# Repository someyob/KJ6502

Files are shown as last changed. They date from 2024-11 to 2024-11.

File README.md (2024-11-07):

# KJ6502
Inspired by the Ben Eater video series.

Note:  the expension header has 2 errors, Pins 15 through 21 should be
A12, A13, A14 and A15 respectively.  These are not intended to be used anyway.



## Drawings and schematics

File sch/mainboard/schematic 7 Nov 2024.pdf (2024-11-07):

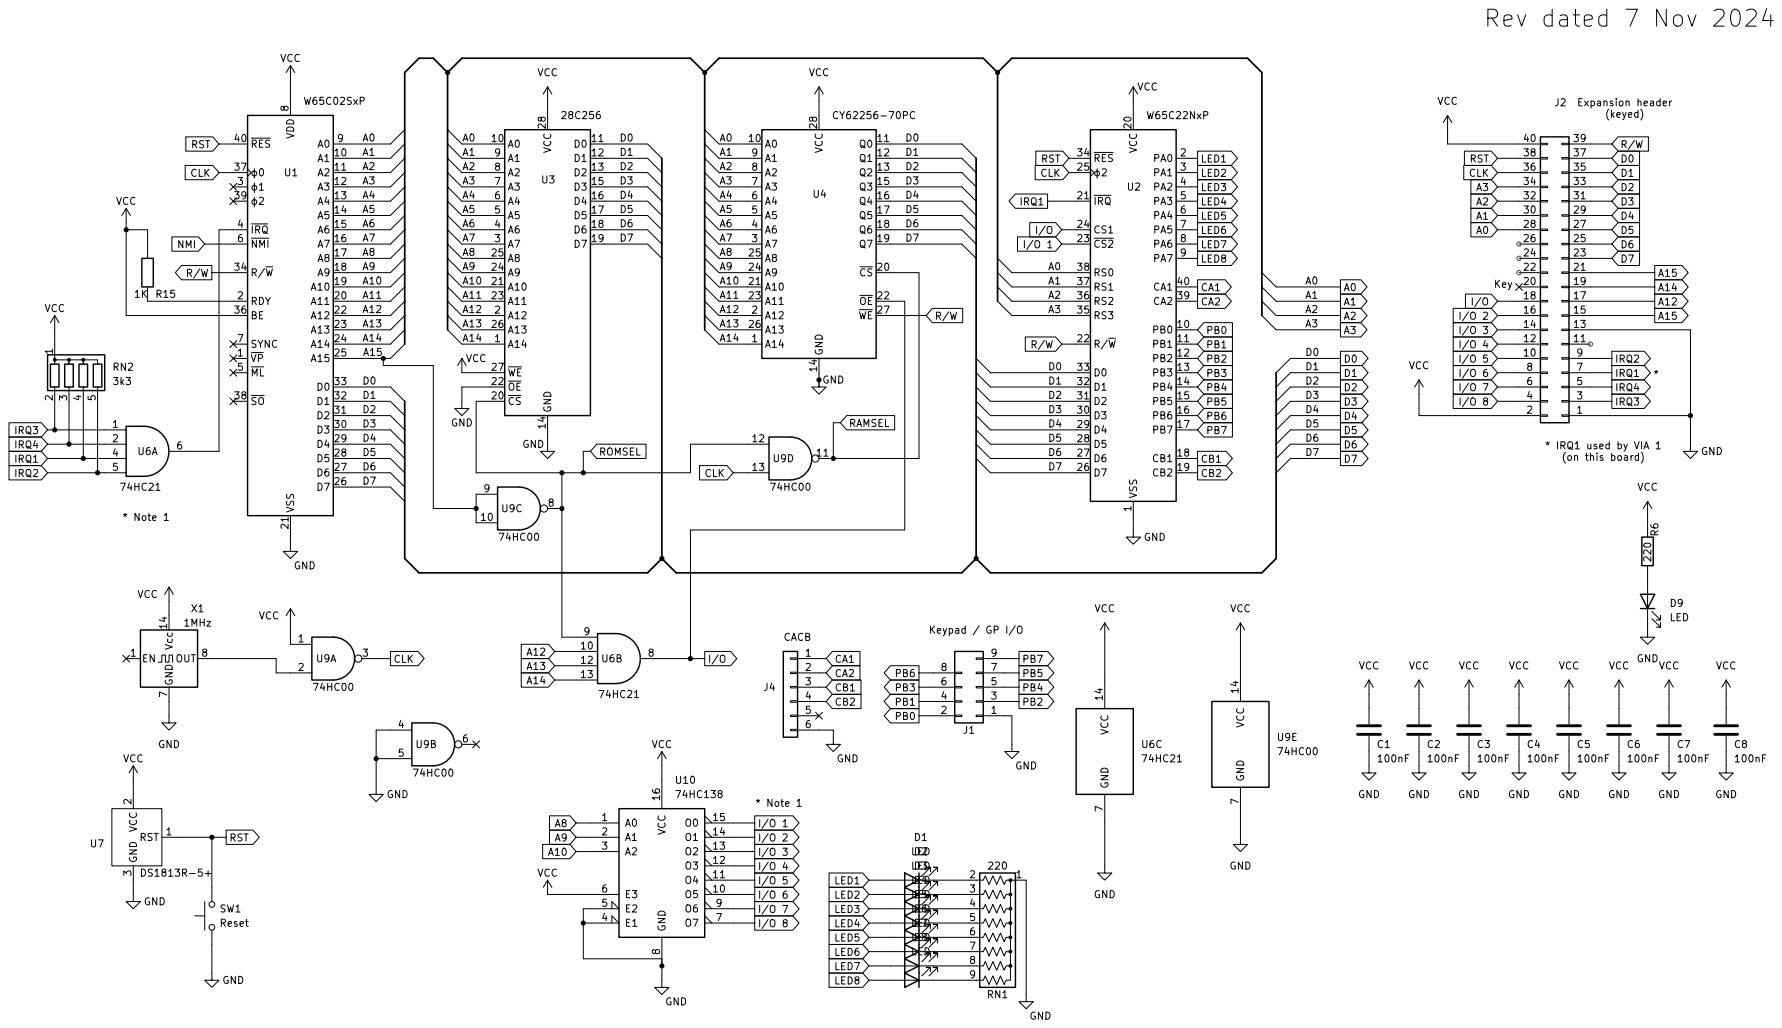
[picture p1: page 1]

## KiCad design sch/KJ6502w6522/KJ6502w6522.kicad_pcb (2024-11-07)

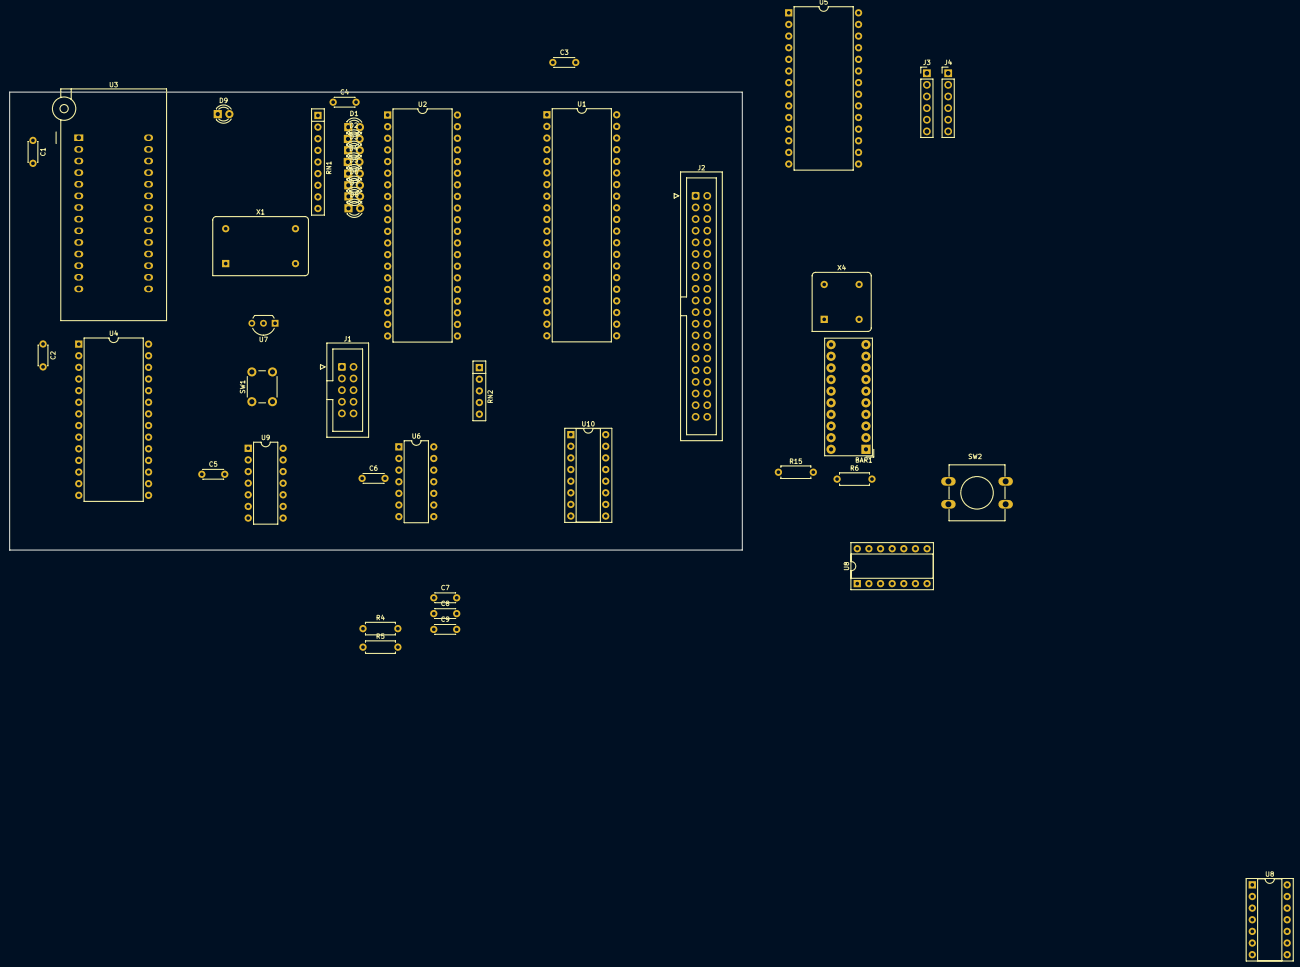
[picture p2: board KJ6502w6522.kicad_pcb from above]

Board: 2 copper layers, 160.0 x 100.0 mm, 44 parts (0 on the bottom side), 75 nets, no tracks yet.

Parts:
BAR1: HDSP-4830_2; HDSP-4830
C1, C2, C3, C4, C5, C6, C7, C8, C9: 100nF; C_Disc_D4.3mm_W1.9mm_P5.00mm
D1, D2, D3, D4, D5, D6, D7, D8, D9: LED; LED_D3.0mm
J1: Keypad / GP I/O; IDC-Header_2x05_P2.54mm_Vertical
J2: Conn_02x20_Odd_Even; IDC-Header_2x20_P2.54mm_Vertical
J3: Serial; PinHeader_1x06_P2.54mm_Vertical
J4: CACB; PinHeader_1x06_P2.54mm_Vertical
R4, R5: 10K; R_Axial_DIN0207_L6.3mm_D2.5mm_P7.62mm_Horizontal
R6: 220; R_Axial_DIN0207_L6.3mm_D2.5mm_P7.62mm_Horizontal
R15: 1K; R_Axial_DIN0207_L6.3mm_D2.5mm_P7.62mm_Horizontal
RN1: 220; R_Array_SIP9
RN2: 3k3; R_Array_SIP5
SW1: Reset; SW_PUSH_6mm
SW2: NMI; SW_PUSH-12mm
U1: W65C02SxP; DIP-40_W15.24mm
U2: W65C22NxP; DIP-40_W15.24mm
U3: 28C256; DIP_Socket-28_W11.9_W12.7_W15.24_W17.78_W18.5_3M_228-1277-0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
U4: CY62256-70PC; DIP-28_W15.24mm
U5: W65C51NxP; DIP-28_W15.24mm
U6: 74HC21; DIP-14_W7.62mm
U7: TO-92L_Inline_Wide
U8, U8#2: 74HC14; DIP-14_W7.62mm_Socket
U9: 74HC00; DIP-14_W7.62mm
U10: 74HC138; DIP-16_W7.62mm_Socket
X1: 1MHz; Oscillator_DIP-14
X4: TFT660; Oscillator_DIP-8

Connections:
/A0: U1.9 (A0), U2.38 (RS0), U3.10 (A0), U4.10 (A0), U5.13 (RS0)
/A1: U1.10 (A1), U2.37 (RS1), U3.9 (A1), U4.9 (A1), U5.14 (RS1)
/A2: U1.11 (A2), U2.36 (RS2), U3.8 (A2), U4.8 (A2)
/A3: U1.12 (A3), U2.35 (RS3), U3.7 (A3), U4.7 (A3)
/A4: U1.13 (A4), U3.6 (A4), U4.6 (A4)
/A5: U1.14 (A5), U3.5 (A5), U4.5 (A5)
/A6: U1.15 (A6), U3.4 (A6), U4.4 (A6)
/A7: U1.16 (A7), U3.3 (A7), U4.3 (A7)
/A11: U1.20 (A11), U3.23 (A11), U4.23 (A11)
/A15: U1.25 (A15), U9.9, U9.10
/D0: U1.33 (D0), U2.33 (D0), U3.11 (D0), U4.11 (Q0), U5.18 (D0)
/D1: U1.32 (D1), U2.32 (D1), U3.12 (D1), U4.12 (Q1), U5.19 (D1)
/D2: U1.31 (D2), U2.31 (D2), U3.13 (D2), U4.13 (Q2), U5.20 (D2)
/D3: U1.30 (D3), U2.30 (D3), U3.15 (D3), U4.15 (Q3), U5.21 (D3)
/D4: U1.29 (D4), U2.29 (D4), U3.16 (D4), U4.16 (Q4), U5.22 (D4)
/D5: U1.28 (D5), U2.28 (D5), U3.17 (D5), U4.17 (Q5), U5.23 (D5)
/D6: U1.27 (D6), U2.27 (D6), U3.18 (D6), U4.18 (Q6), U5.24 (D6)
/D7: U1.26 (D7), U2.26 (D7), U3.19 (D7), U4.19 (Q7), U5.25 (D7)
A8: U1.17 (A8), U3.25 (A8), U4.25 (A8), U10.1 (A0)
A9: U1.18 (A9), U3.24 (A9), U4.24 (A9), U10.2 (A1)
A10: U1.19 (A10), U3.21 (A10), U4.21 (A10), U10.3 (A2)
A12: U1.22 (A12), U3.2 (A12), U4.2 (A12), U6.10
A13: U1.23 (A13), U3.26 (A13), U4.26 (A13), U6.12
A14: U1.24 (A14), U3.1 (A14), U4.1 (A14), U6.13
CA1: J4.1, U2.40 (CA1)
CA2: J4.2, U2.39 (CA2)
CB1: J4.3, U2.18 (CB1)
CB2: J4.4, U2.19 (CB2)
CLK: U1.37 (ϕ0), U2.25 (ϕ2), U5.27 (ϕ2), U9.13, X1.8 (OUT)
GND: C1.2, C2.2, C3.2, C4.2, C5.2, C6.2, C7.2, C8.2, C9.2, D9.1 (K), J1.1, J3.2, J4.6, RN1.1 (common), SW1.1, SW2.1, U1.21 (VSS), U2.1 (VSS), U3.14 (GND), U3.22 (~OE), U4.14 (GND), U5.1 (VSS), U5.9 (~CTS), U5.16 (~DCD), U5.17 (~DSR), U6.7 (GND), U7.3 (GND), U9.7 (GND), U10.4 (E1), U10.5 (E2), U10.8 (GND), X1.7 (GND), X4.4 (GND)
IRQ1: RN2.4 (R3), U2.21 (~IRQ), U6.4
IRQ2: RN2.5 (R4), U5.26 (~IRQ), U6.5
IRQ3: RN2.2 (R1), U6.1
IRQ4: RN2.3 (R2), U6.2
I/O: U2.24 (CS1), U4.22 (~OE), U5.2 (CS1), U6.8
I/O 1: U2.23 (~CS2), U10.15 (O0)
I/O 2: U5.3 (~CS2), U10.14 (O1)
LED1: BAR1.3 (A), D1.2 (A), U2.2 (PA0)
LED2: BAR1.4 (A), D2.2 (A), U2.3 (PA1)
LED3: BAR1.5 (A), D3.2 (A), U2.4 (PA2)
LED4: BAR1.6 (A), D4.2 (A), U2.5 (PA3)
LED5: BAR1.7 (A), D5.2 (A), U2.6 (PA4)
LED6: BAR1.8 (A), D6.2 (A), U2.7 (PA5)
LED7: BAR1.9 (A), D7.2 (A), U2.8 (PA6)
LED8: BAR1.10 (A), D8.2 (A), U2.9 (PA7)
NMI: U1.6 (~NMI), U8#2.12
unnamed: C9.1, R5.1, U8#2.13
unnamed: D1.1 (K), RN1.2 (R1)
unnamed: D2.1 (K), RN1.3 (R2)
unnamed: D3.1 (K), RN1.4 (R3)
unnamed: D4.1 (K), RN1.5 (R4)
unnamed: D5.1 (K), RN1.6 (R5)
unnamed: D6.1 (K), RN1.7 (R6)
unnamed: D7.1 (K), RN1.8 (R7)
unnamed: D8.1 (K), RN1.9 (R8)
unnamed: D9.2 (A), R6.2
unnamed: J3.3, U5.12 (RxD)
unnamed: J3.4, U5.10 (TxD)
unnamed: R4.2, R5.2, SW2.2
unnamed: R15.2, U1.2 (RDY)
unnamed: U1.4 (~IRQ), U6.6
unnamed: U5.6 (XTAL1), X4.5 (OUT)
PB0: J1.2, U2.10 (PB0)
PB1: J1.3, U2.11 (PB1)
PB2: J1.4, U2.12 (PB2)
PB3: J1.5, U2.13 (PB3)
PB4: J1.6, U2.14 (PB4)
PB5: J1.7, U2.15 (PB5)
PB6: J1.8, U2.16 (PB6)
PB7: J1.9, U2.17 (PB7)
RAMSEL: U4.20 (~CS), U9.11
ROMSEL: U3.20 (~CS), U6.9, U9.8, U9.12
RST: SW1.2, U1.40 (~RES), U2.34 (~RES), U5.4 (~RES), U7.1 (RST)
R/W: U1.34 (R/~W), U2.22 (R/~W), U4.27 (~WE), U5.28 (R/~W)
VCC: BAR1.1 (A), C1.1, C2.1, C3.1, C4.1, C5.1, C6.1, C7.1, C8.1, R4.1, R6.1, R15.1, RN2.1 (common), U1.8 (VDD), U1.36 (BE), U2.20 (VCC), U3.27 (~WE), U3.28 (VCC), U4.28 (VCC), U5.15 (VCC), U6.14 (VCC), U7.2 (VCC), U9.14 (VCC), U10.6 (E3), U10.16 (VCC), X1.14 (Vcc), X4.8 (Vcc)
